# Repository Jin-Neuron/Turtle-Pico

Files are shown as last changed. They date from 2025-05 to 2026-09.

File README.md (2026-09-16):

<div align="right">
  <a href="README_en.md">English</a> | <b>日本語</b>
</div>

# Turtle Pico - 配線いらずで、本格的な電子工作を -

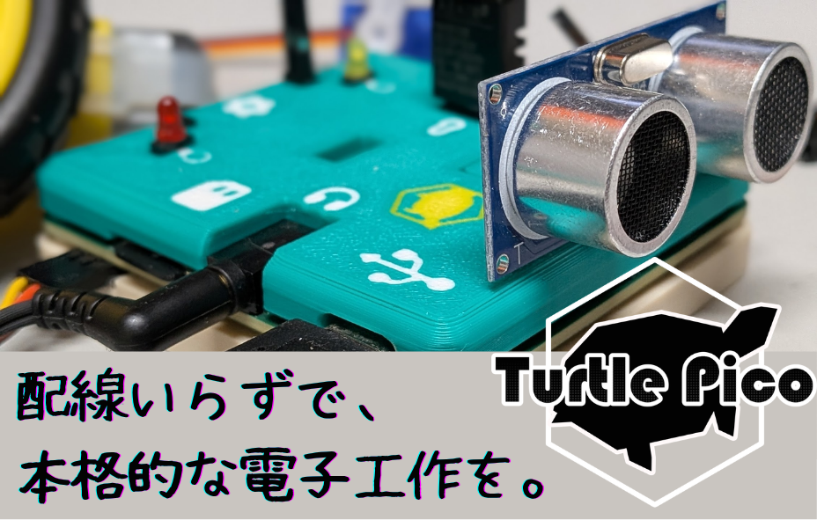
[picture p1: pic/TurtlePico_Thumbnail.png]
Turtle Pico


こんにちは！皆さんは、**電子工作でのお困りごと**を、どのように解決しますか？

煩雑な配線、難しいプログラミングと困難な環境構築、毎回確認が面倒なピン配置...などなど、電子工作を楽しんでいると、いくつもの壁に突き当たります。

そんな課題を克服できるようにと開発したのが、このTurtle Pico マイコンボード。ブレッドボードすら不要で、**コネクタに直接部品を接続するだけ**で回路が完成します。内部には**Raspberry Pi Pico W**を搭載しているので、プログラミングには**MicroPython**を使用でき、更にリソースにも困りません！

コネクタに超音波センサを指すと、その容姿はまるで亀のようで、その容姿から「**Turtle Pico**」とボードを名付けました。

ボードの詳細仕様は、 [Turtle Pico 仕様書](https://jinproduction.work/wp-content/uploads/2024/07/specific_ja.pdf)をご覧ください！

**本PJは現在、製品化に向けて準備中です。**

## Turtle Pico 製品パッケージ

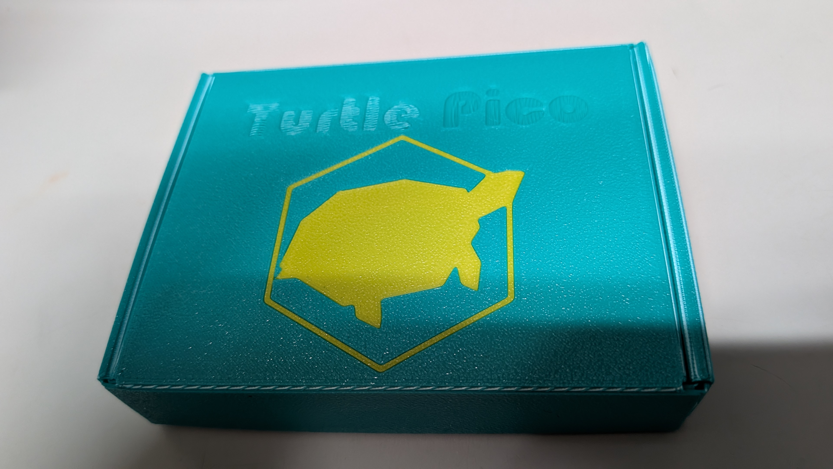
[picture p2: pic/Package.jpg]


Turtle Picoは、画像のような**パッケージ**に収納されています。

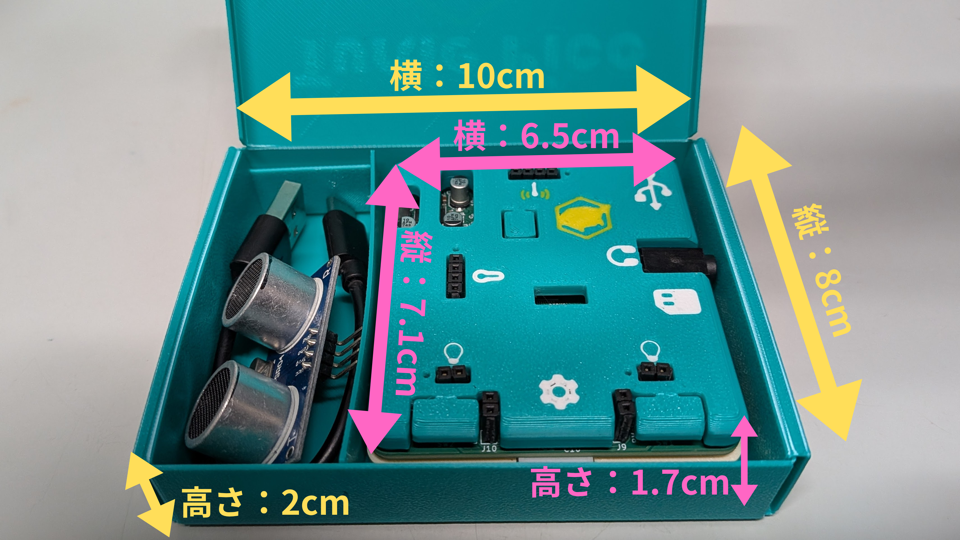
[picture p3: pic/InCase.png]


中を開けるとこのようになっていて、本体と外箱の寸法は画像に記載のとおりです。黄色が外箱、ピンクが本体の寸法です。

パッケージの中に、更にTurtle Pico本体がありますが、本体は基板を**オリジナル3Dプリンタ製カバー**で覆うような形状をしています。USBやMicroSDカードなどのコネクタポートがロゴで表示されています。

それぞれの意味は、[Turtle Pico 仕様書](https://jinproduction.work/wp-content/uploads/2024/07/specific_ja.pdf) にてご確認ください。

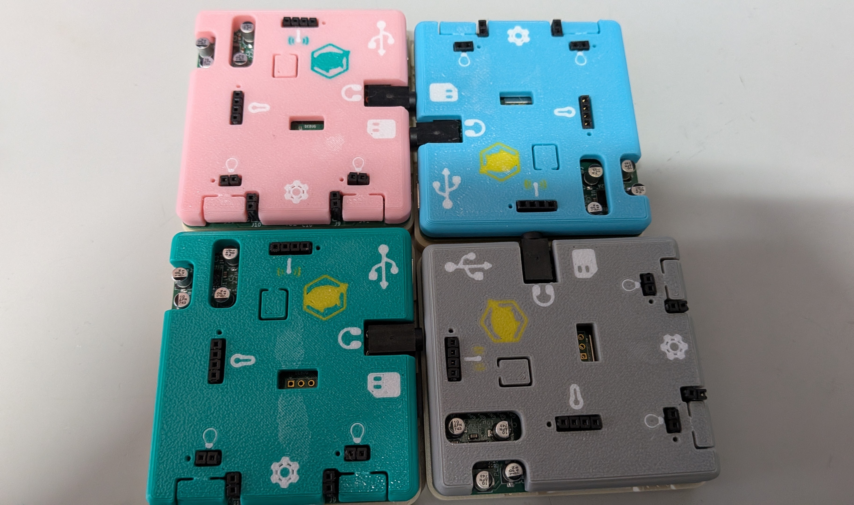
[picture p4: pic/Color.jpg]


Turtle Picoは本体カバーの色で**カラーバリエーション**が4色あり、**ピンク色、緑色、グレー、空色**となっています。

## Turtle Pico ワクワク作例ブック

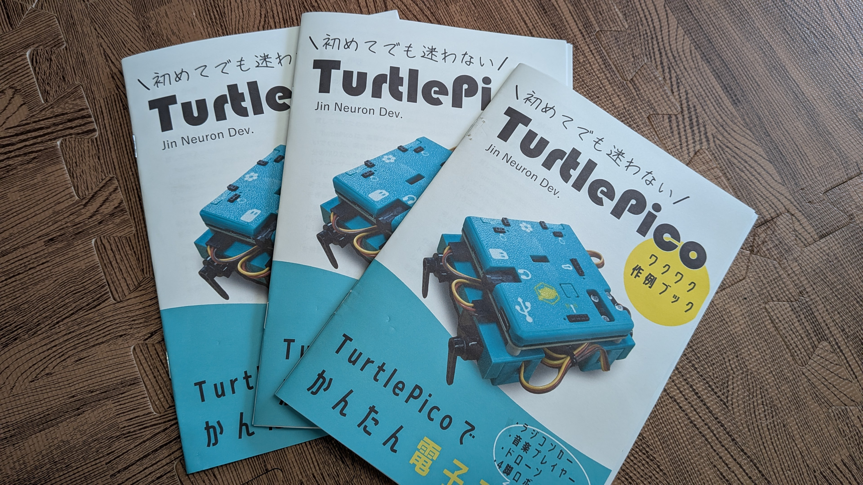
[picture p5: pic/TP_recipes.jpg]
Recipes


製品化モデルでは、上記の作例集が付属します。ソースコードを [example](./example/)に掲載している、TurtlePico作例の数々の作り方を掲載しています。

ここでは、作例集に掲載している、いくつかの**Turtle Picoの仲間たち**をご紹介しましょう。

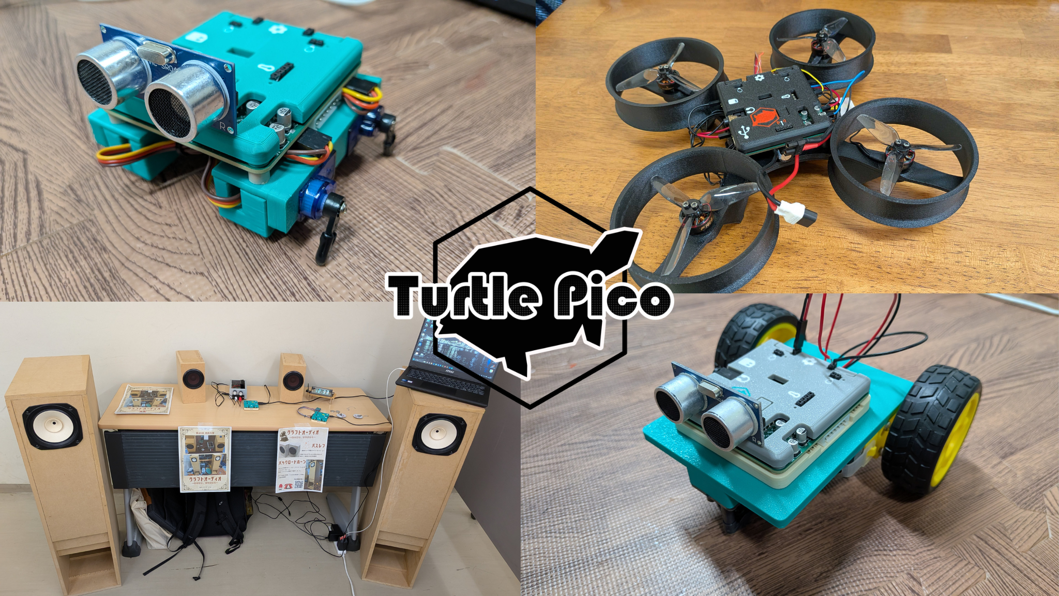
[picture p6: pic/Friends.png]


画像左上は4脚でよちよちと歩くロボット「**Turtle Pico Robot**」で、サーボモータの回転で歩きます。その右側にあるのはドローン「**Turtle Pico Drone**」、更にその下にはマイコンカー「**Turtle Pico Car**」があります。

これらは、上に乗せるものを変えたり、様々な制御を追加することで、**いろいろな応用**が効きそうです。ぜひ、作例集を参考に、**自分専用のアプリケーション**に仕上げてください！

画像左下には、Turtle Picoを**サウンドカード**にしてスピーカーで音楽を流している作例です。Turtle Picoに搭載されているPCM5102AというオーディオDACは、**32bit / 192kHz**にも対応しているため、ハイレゾ音源も流せるパワフルなオーディオDACとなります。

従って、TurtlePicoは、公式にある**サウンドカード**のファームウェアを使用すれば、周囲にアンプやスピーカーをつないで、**クラフトオーディオ**を楽しむことができるボードにもなります。

作例集では、これら作例の作り方を始めとし、**応用の仕方を設計からデバッグまで**、最近の「**バイブコーディング**」でかんたんに行う**製作方法**を解説しています。Turtle Picoをお買い上げいただければ、セット担っているので、ぜひお買い求めください！

<!-- 

## Case

![case](board/main/pic/Case2.PNG)

Turtle Pico Package is available in [**board/main/Case**](https://github.com/Jin-Neuron/Turtle-Pico/tree/master/board/main/Case).

## Purchase your board

![image](https://github.com/user-attachments/assets/7ed59ffb-0fa4-4088-b02c-0e429f06822e)

Turtle Pico boards can currently only be purchased from [PCBWay's Shared Project Page](https://www.pcbway.com/project/shareproject/Turtle_Pico_Board_c183b11f.html). Once officially released, we plan to make it available for purchase at various online stores. 

-->

## License

本公式リポジトリは、複数のライセンスにて構成されています。

[LICENSE File](License.txt)にてご確認ください。

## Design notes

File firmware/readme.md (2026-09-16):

 build command
 
`$ cd path/to/micropython/ports/rp2`
 
`$ make BOARD=TurtlePico BOARD_DIR=../../../Turtle-Pico/firmware/board_TurtlePico_W USER_C_MODULES=../../../Turtle-Pico/firmware/micropython.cmake -j4`

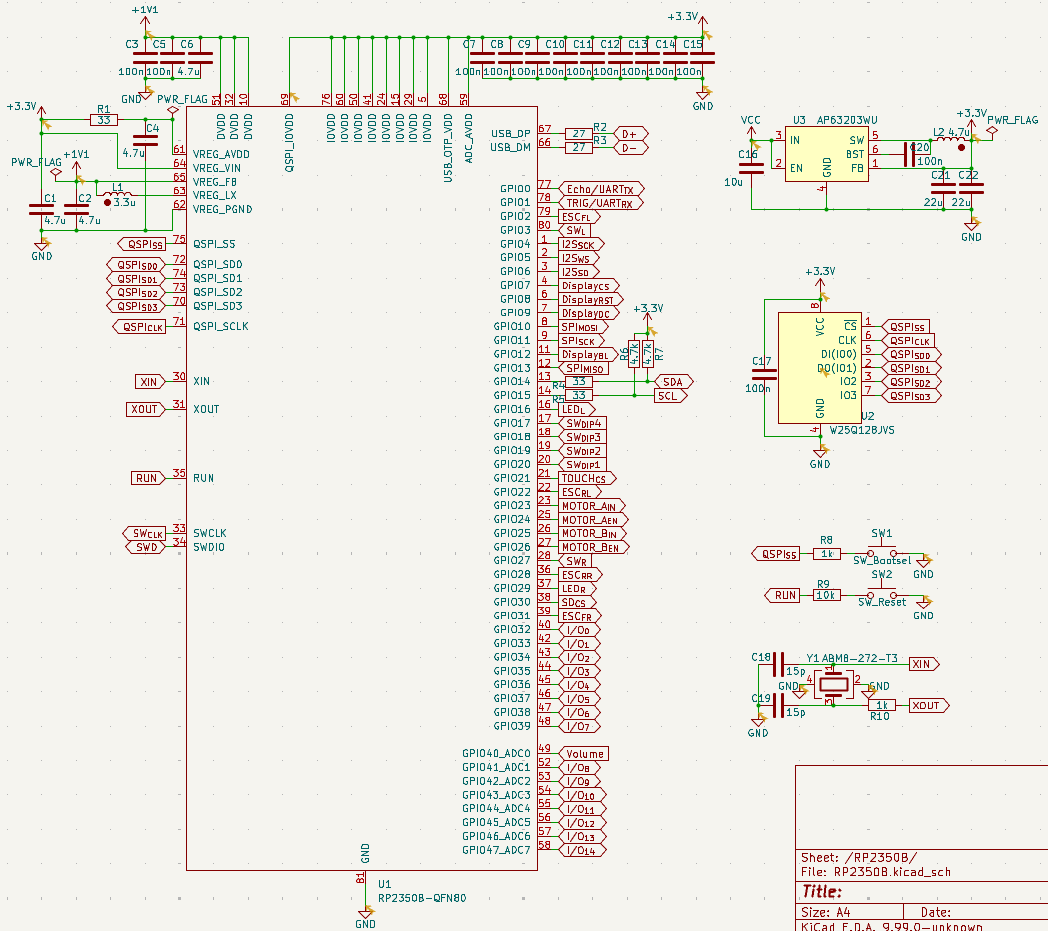
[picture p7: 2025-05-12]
board/advanced/pic/schematics/MainPart_RP2350B.png

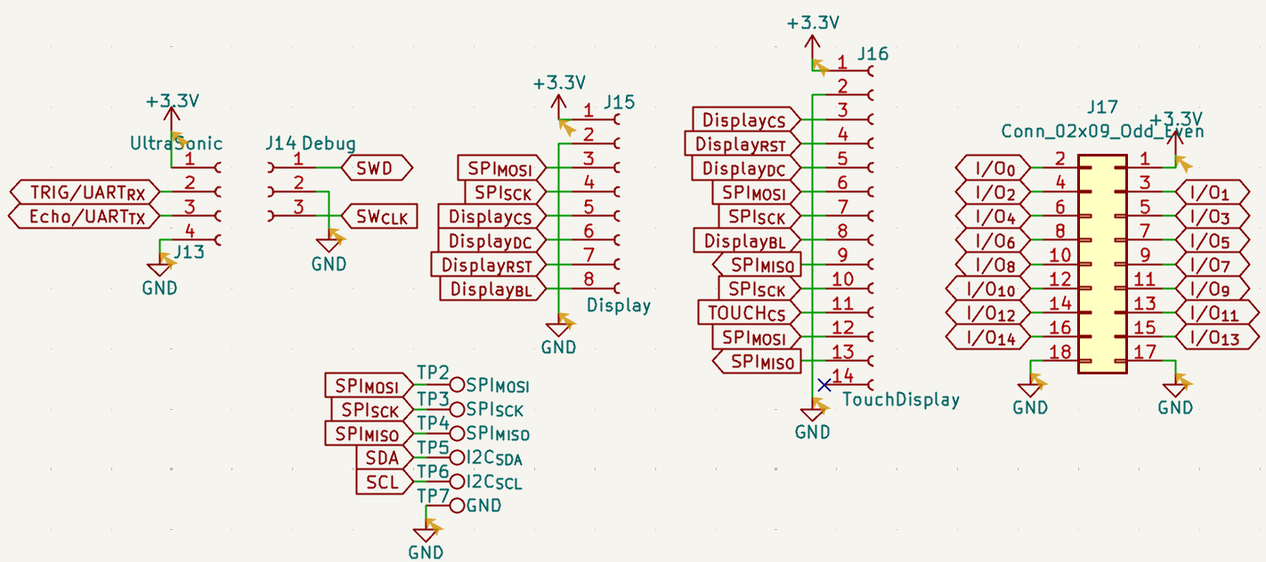
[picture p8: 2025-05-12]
board/advanced/pic/schematics/ConnectorPart.png

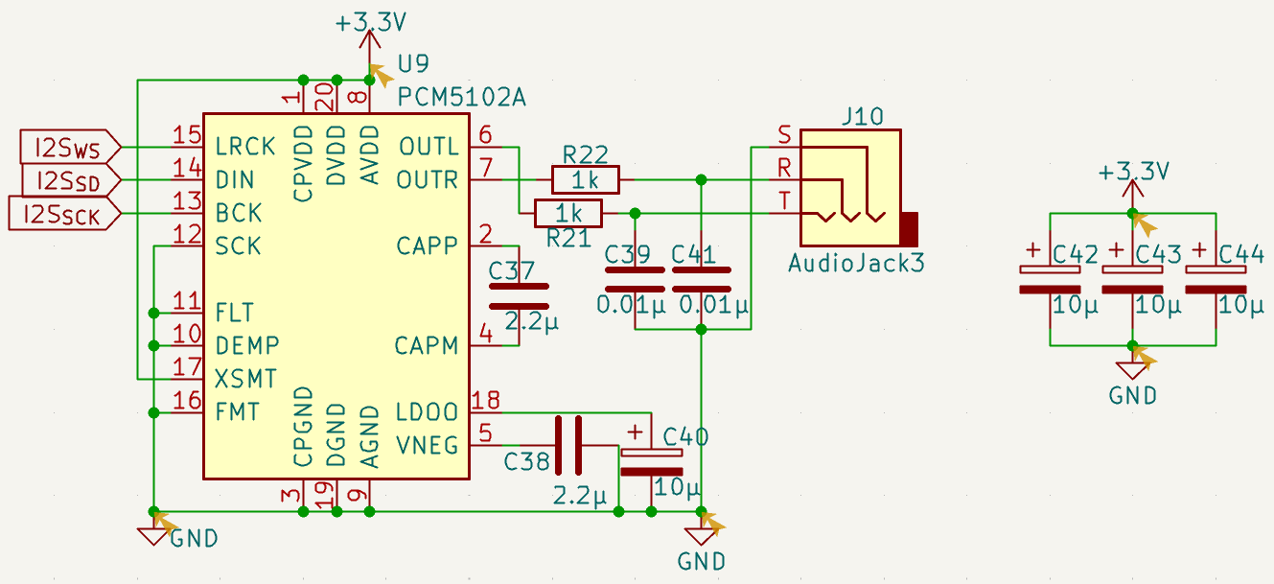
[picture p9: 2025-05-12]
board/advanced/pic/schematics/AudioPart.png

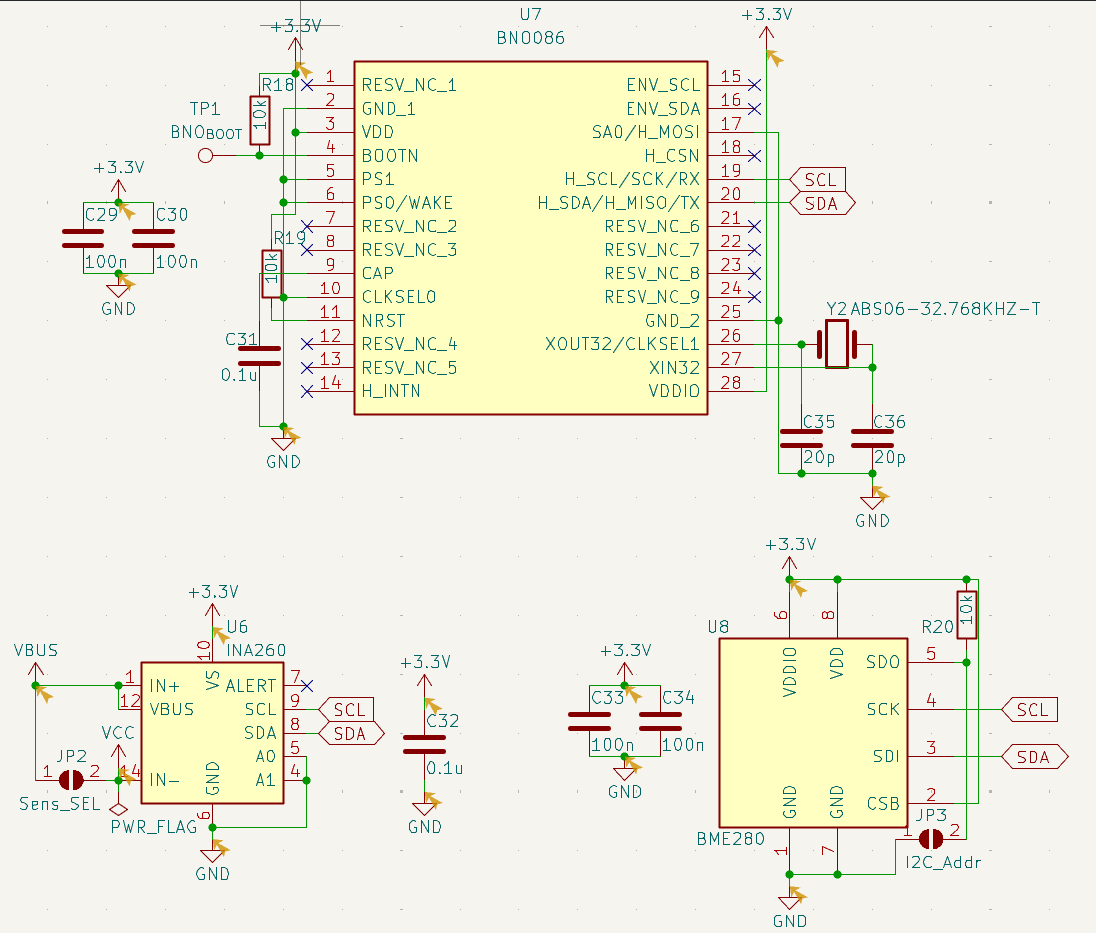
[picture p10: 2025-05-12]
board/advanced/pic/schematics/SensorPart.png

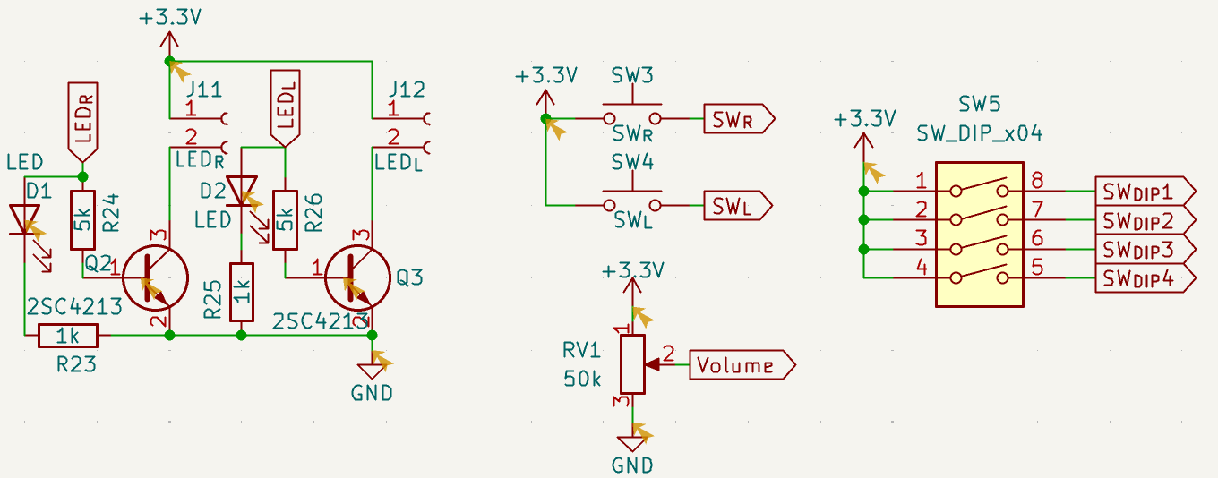
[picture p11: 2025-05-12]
board/advanced/pic/schematics/LED_SW_Part.png

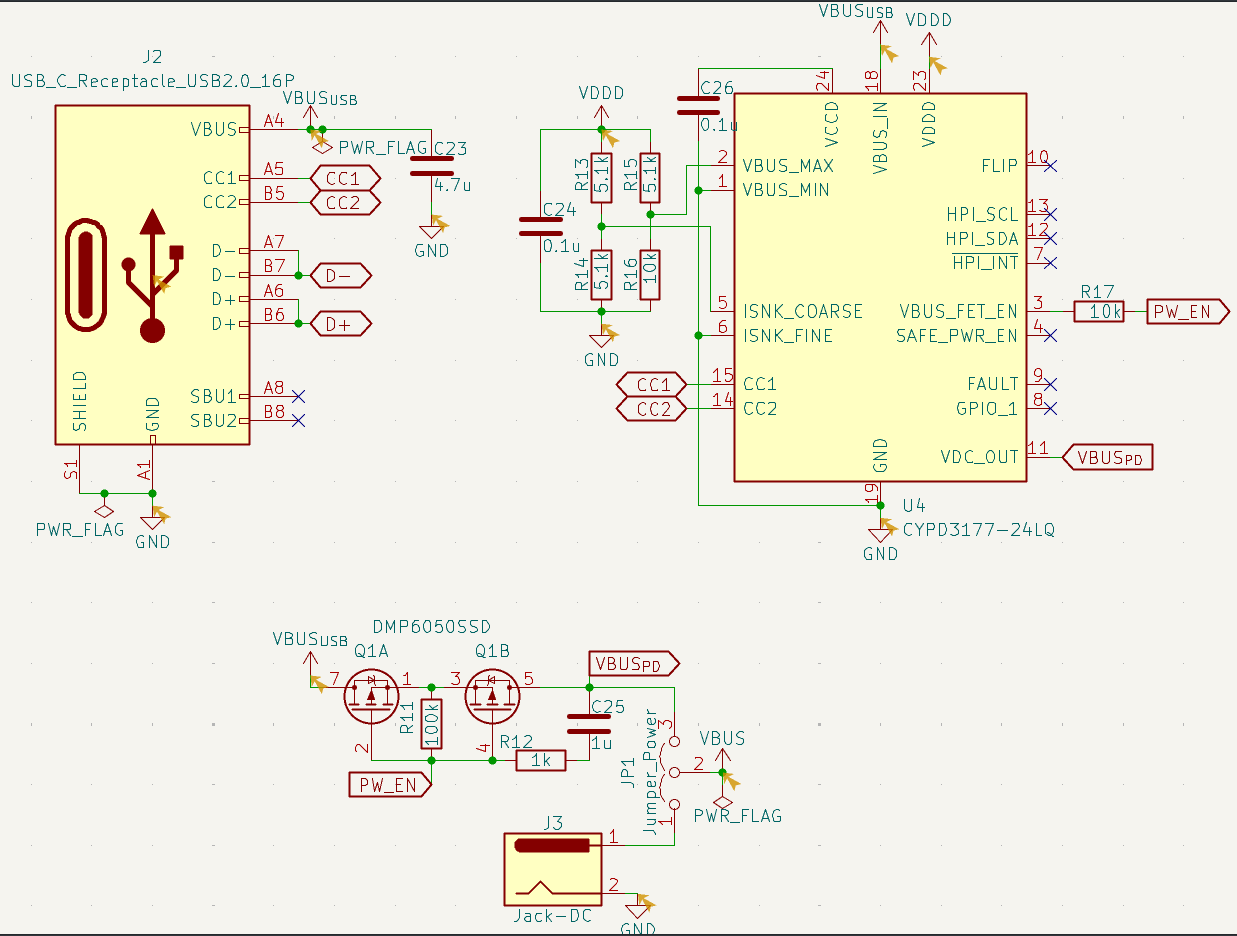
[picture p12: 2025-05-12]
board/advanced/pic/schematics/PowerPart.png

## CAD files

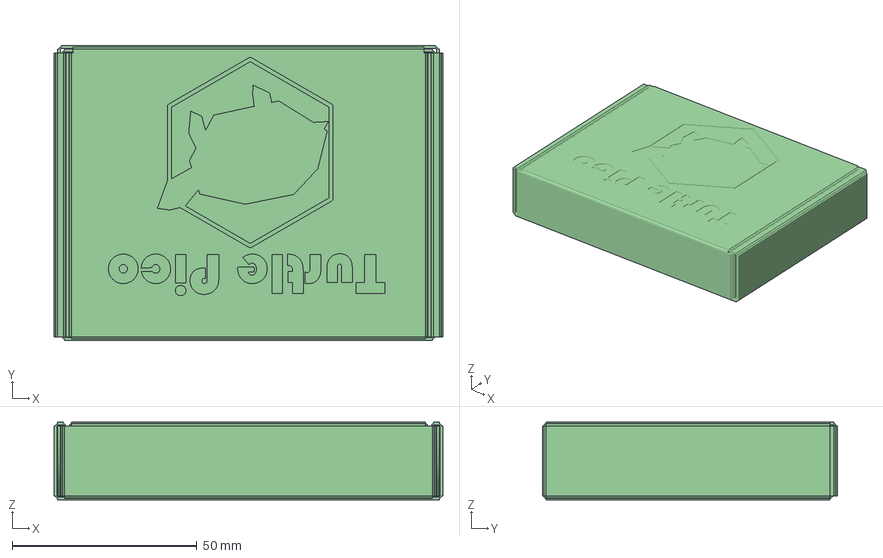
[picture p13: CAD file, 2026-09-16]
board/main/Case/Package_Base_asm.3mf
105.4 x 80.0 x 21.0 mm

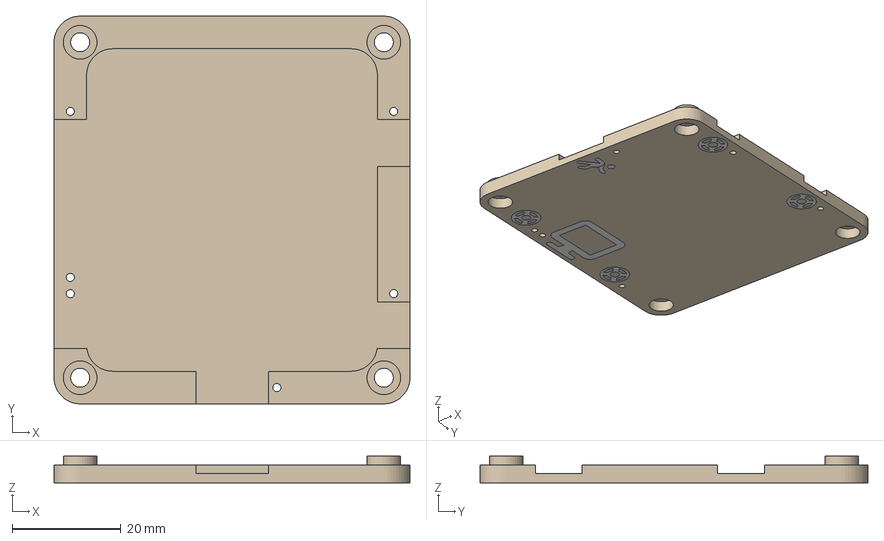
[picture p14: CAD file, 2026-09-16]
board/main/Case/LowerCase_LowQI.3mf
65.5 x 71.3 x 4.89 mm
ボディ1
ボディ2
ボディ3
ボディ4
ボディ5
ボディ6
ボディ7
ボディ9
下段

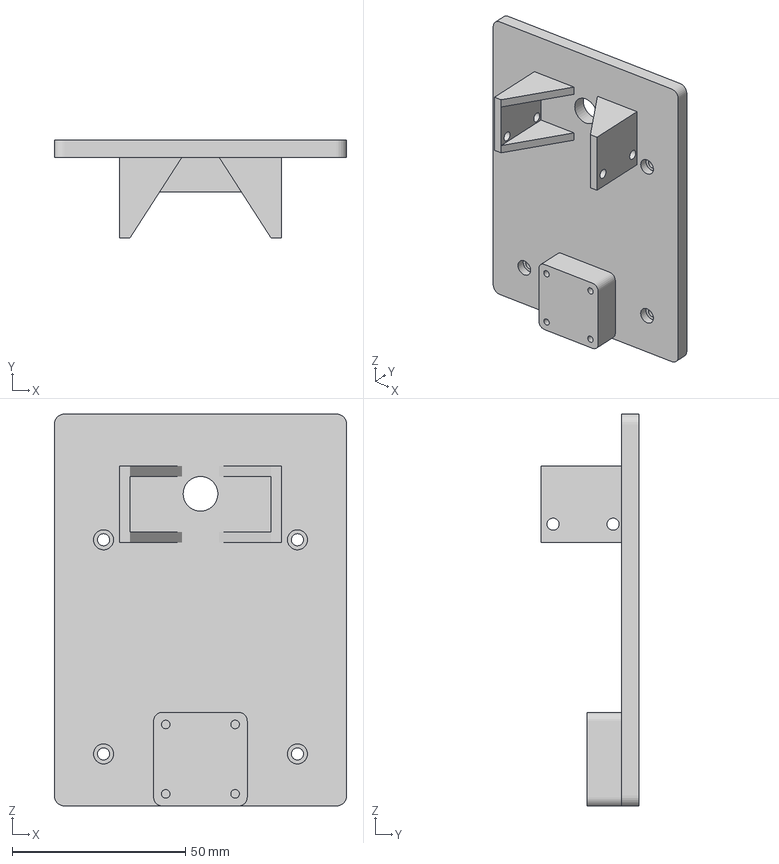
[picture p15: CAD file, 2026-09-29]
example/Car/3D_Data/CarBody.3mf
84.3 x 28.3 x 113.0 mm

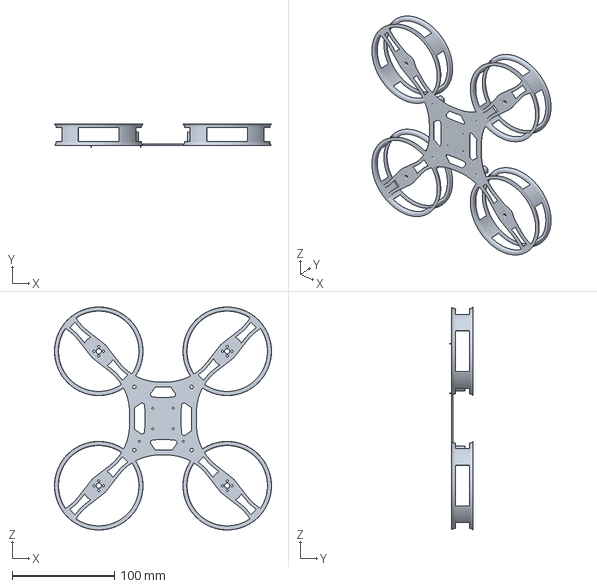
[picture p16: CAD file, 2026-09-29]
example/Drone/3D_Data/DroneUpper.3mf
212.0 x 22.8 x 217.8 mm

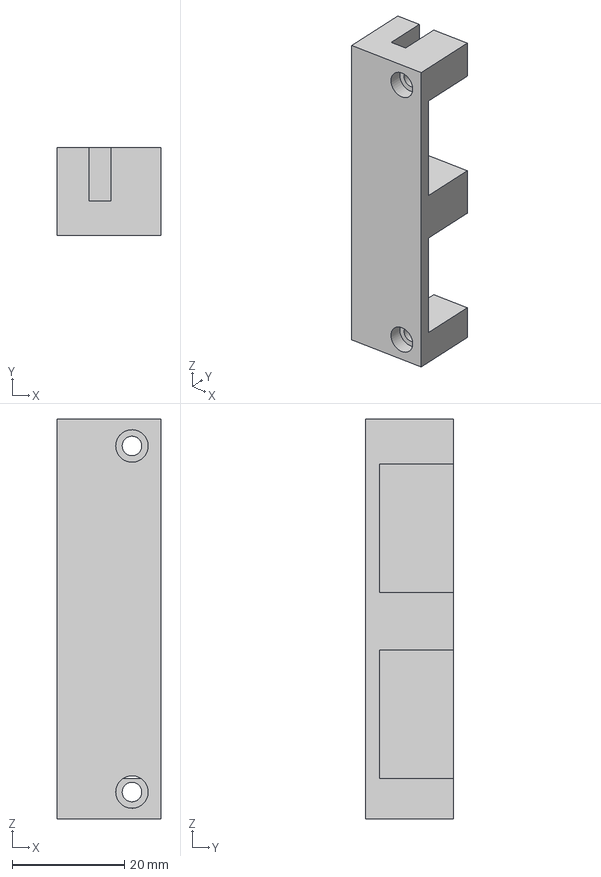
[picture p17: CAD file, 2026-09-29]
example/Robot/3D_Data/Bottom.3mf
18.5 x 15.7 x 71.3 mm

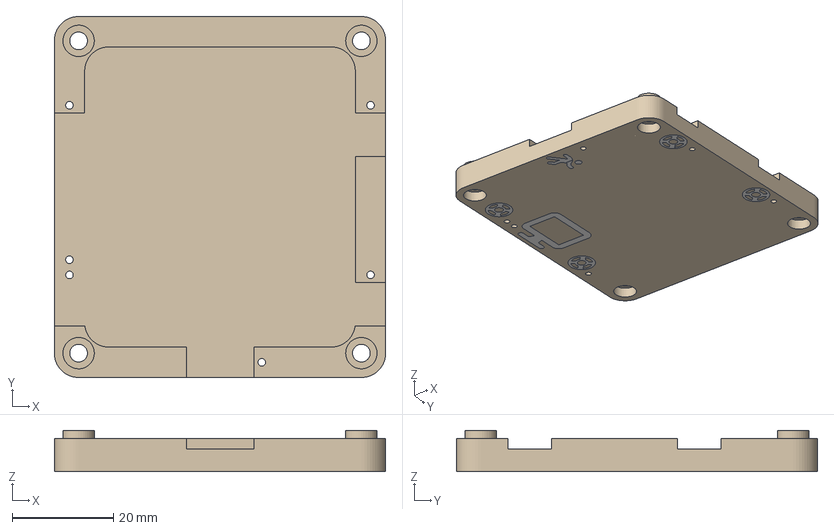
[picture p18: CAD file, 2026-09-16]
board/main/Case/LowerCase_HighQI.3mf
65.5 x 71.3 x 8.19 mm
ボディ1
ボディ2
ボディ3
ボディ4
ボディ5
ボディ6
ボディ7
ボディ9
下段

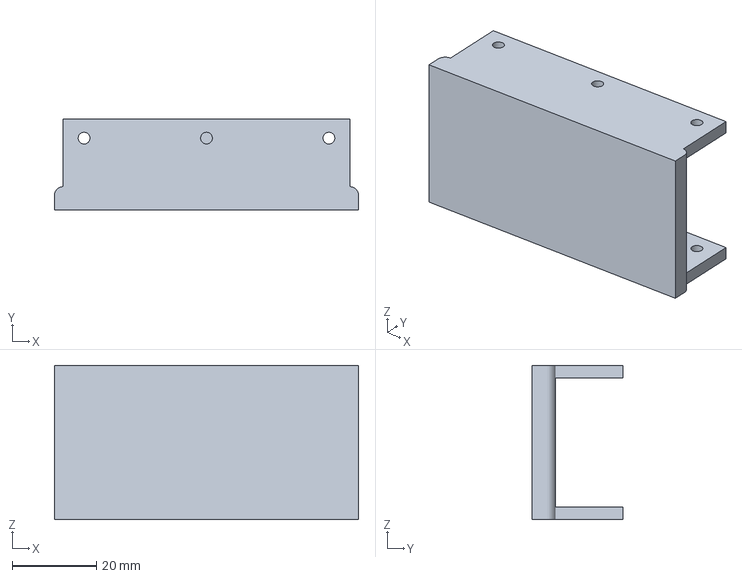
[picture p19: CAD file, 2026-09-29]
example/Drone/3D_Data/BatCase.3mf
72.0 x 21.5 x 36.5 mm

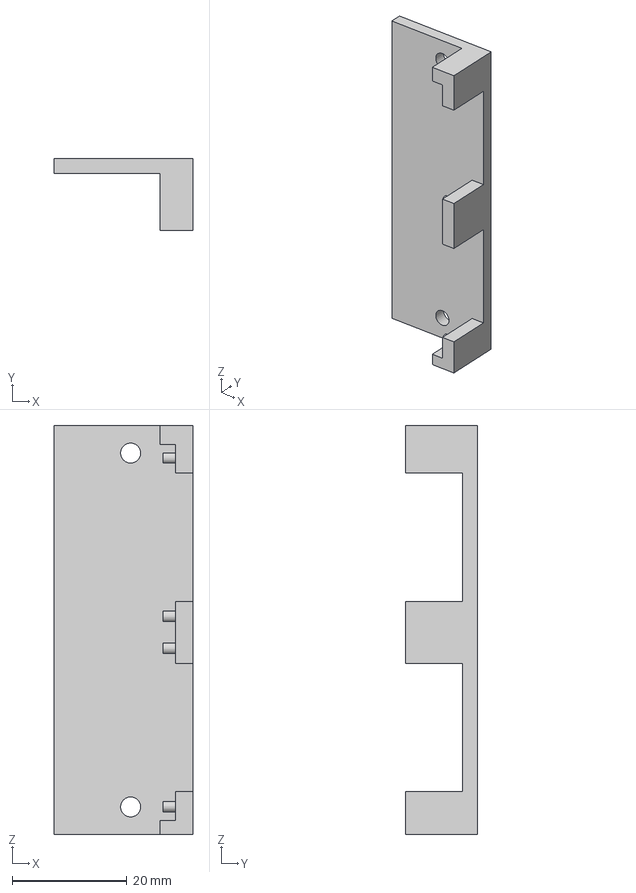
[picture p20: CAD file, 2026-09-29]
example/Robot/3D_Data/Top.3mf
24.2 x 12.6 x 71.3 mm

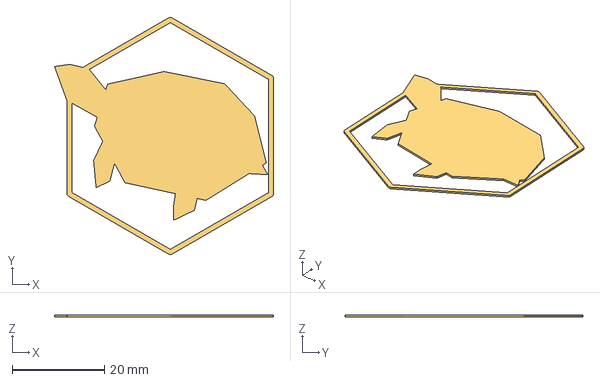
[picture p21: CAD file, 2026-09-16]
board/main/Case/Package_Logo.3mf
47.6 x 51.6 x 0.4 mm

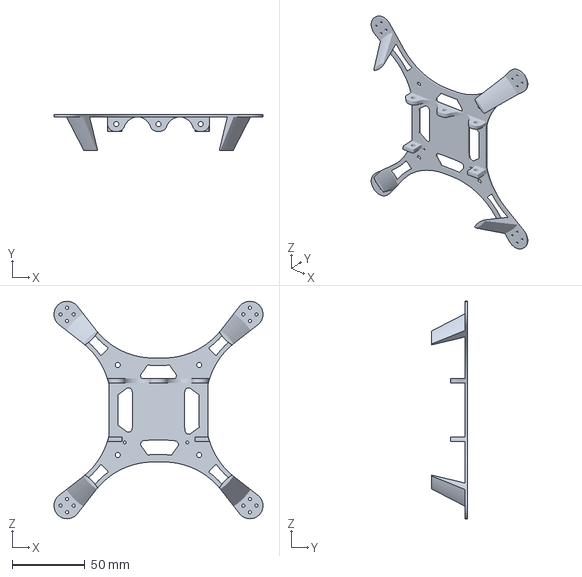
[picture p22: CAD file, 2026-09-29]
example/Drone/3D_Data/DroneBottom_v2.3mf
143.5 x 24.5 x 149.3 mm

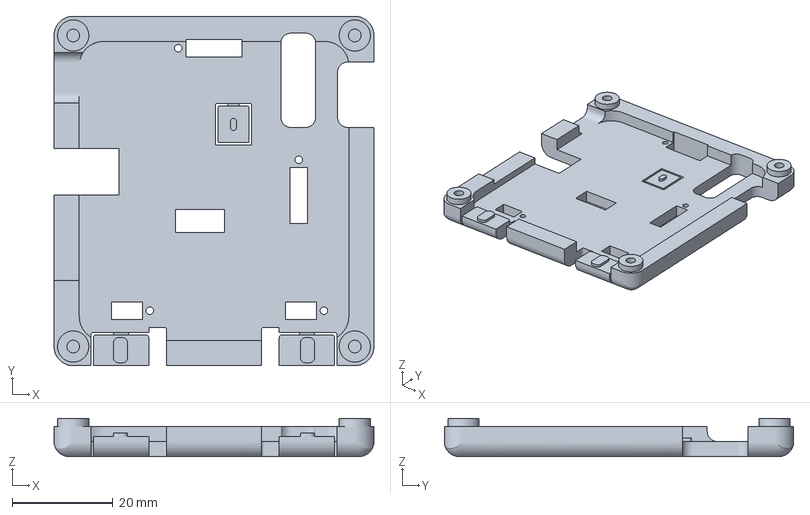
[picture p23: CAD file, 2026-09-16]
board/main/Case/UpperCase.3mf
63.5 x 69.3 x 7.60 mm

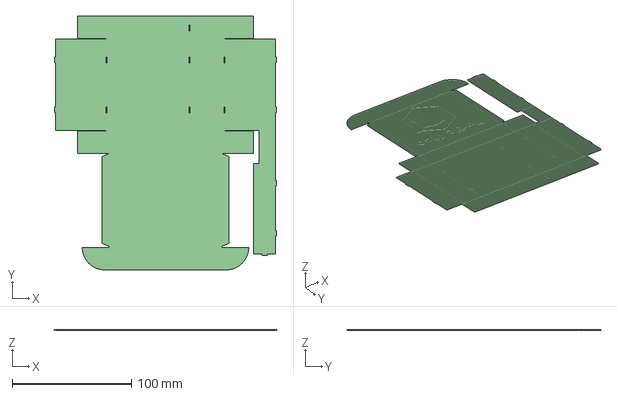
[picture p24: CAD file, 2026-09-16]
board/main/Case/Package_Base.3mf
186.5 x 213.3 x 0.8 mm

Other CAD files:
board/main/TurtlePico_nw/TurtlePico_nw.step
board/main/TurtlePico_v1.2.step
board/main/Case/LowerCase_XH.3mf
board/main/TurtlePico_v1.1.step
board/main/Case/UpperCase_old.step
board/main/Case/LowerCase_old.step

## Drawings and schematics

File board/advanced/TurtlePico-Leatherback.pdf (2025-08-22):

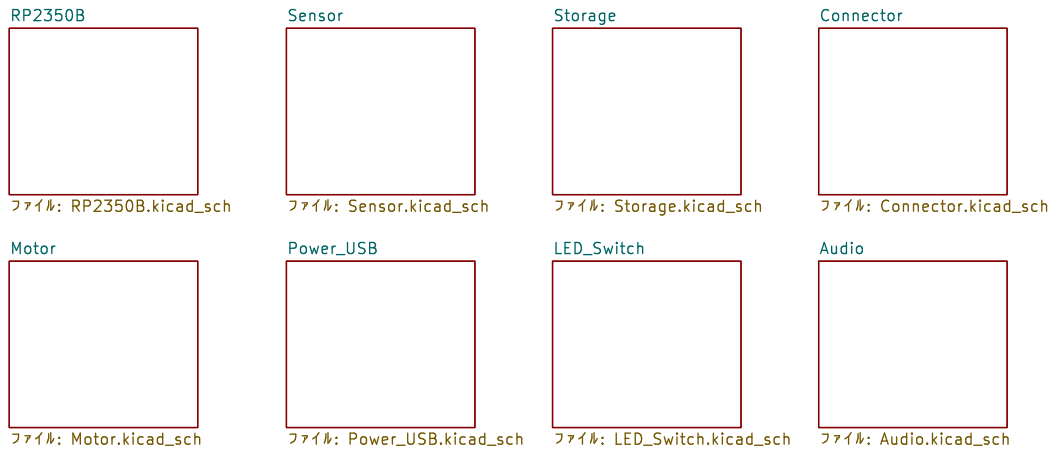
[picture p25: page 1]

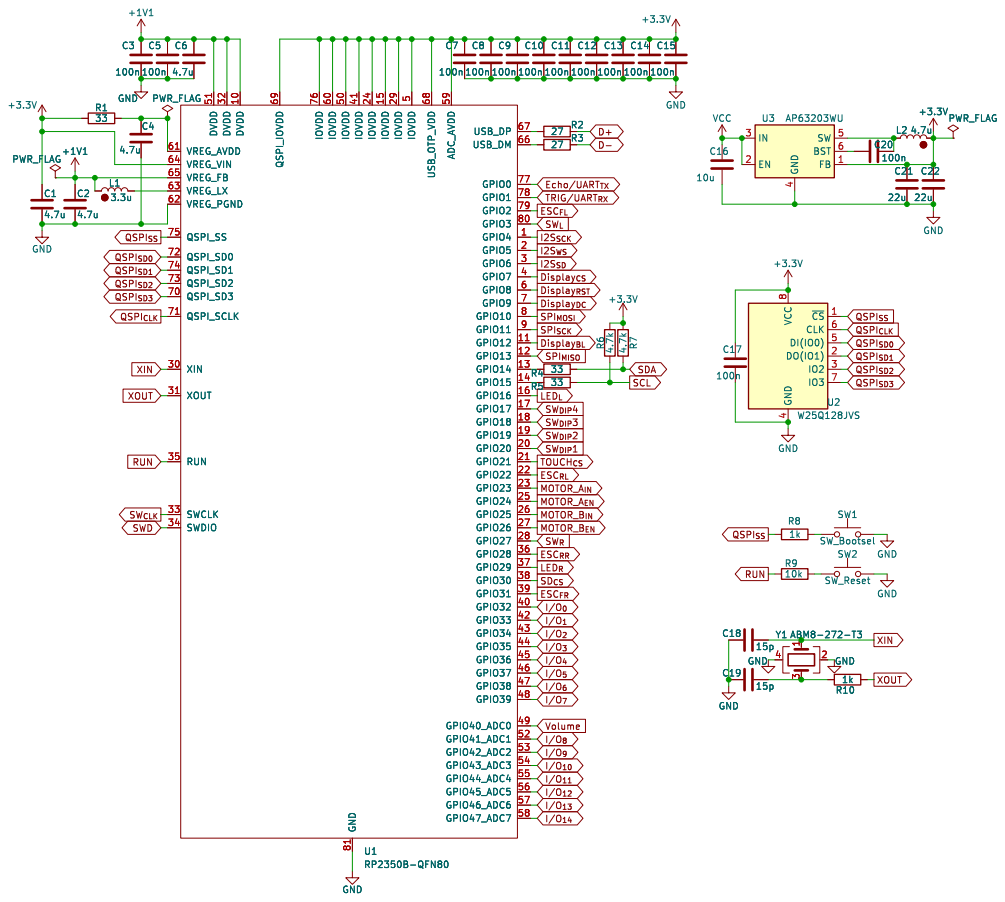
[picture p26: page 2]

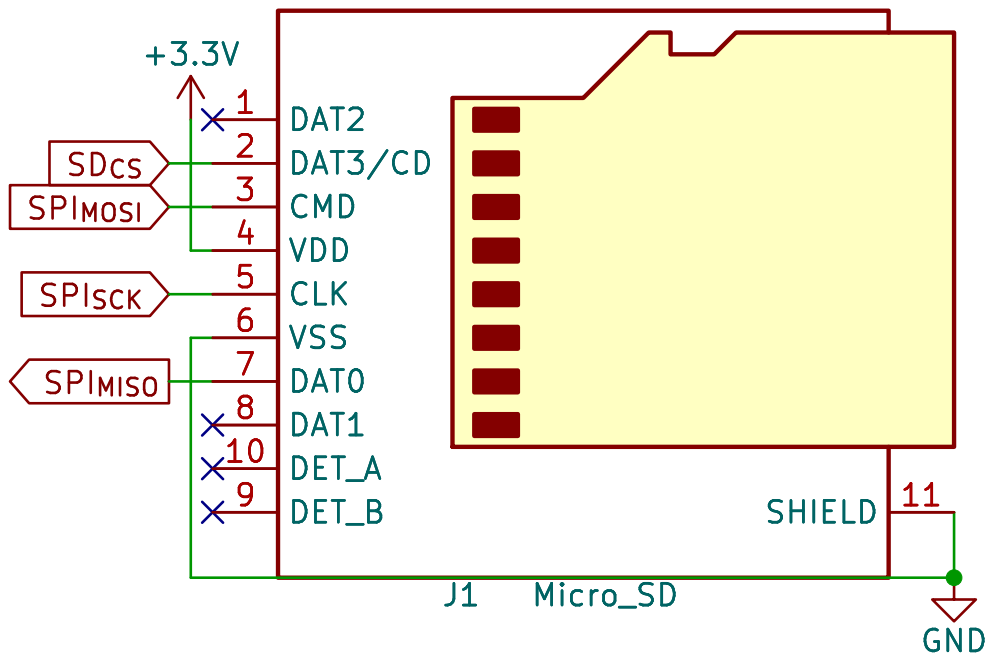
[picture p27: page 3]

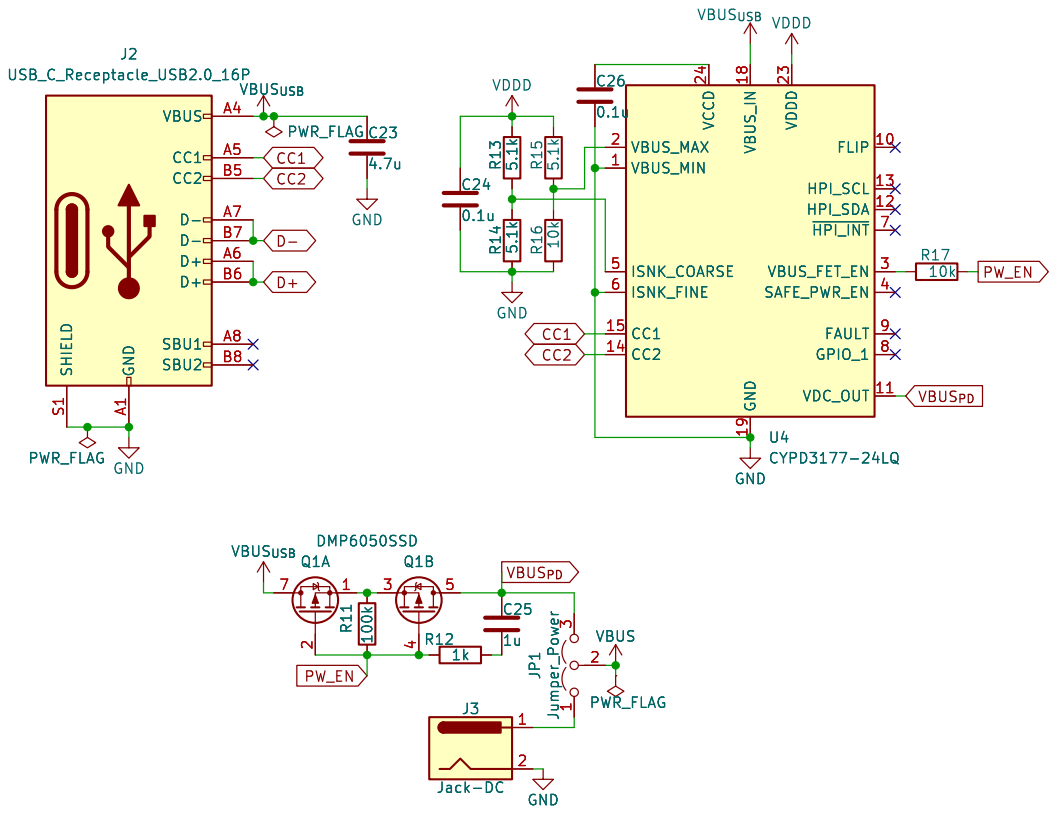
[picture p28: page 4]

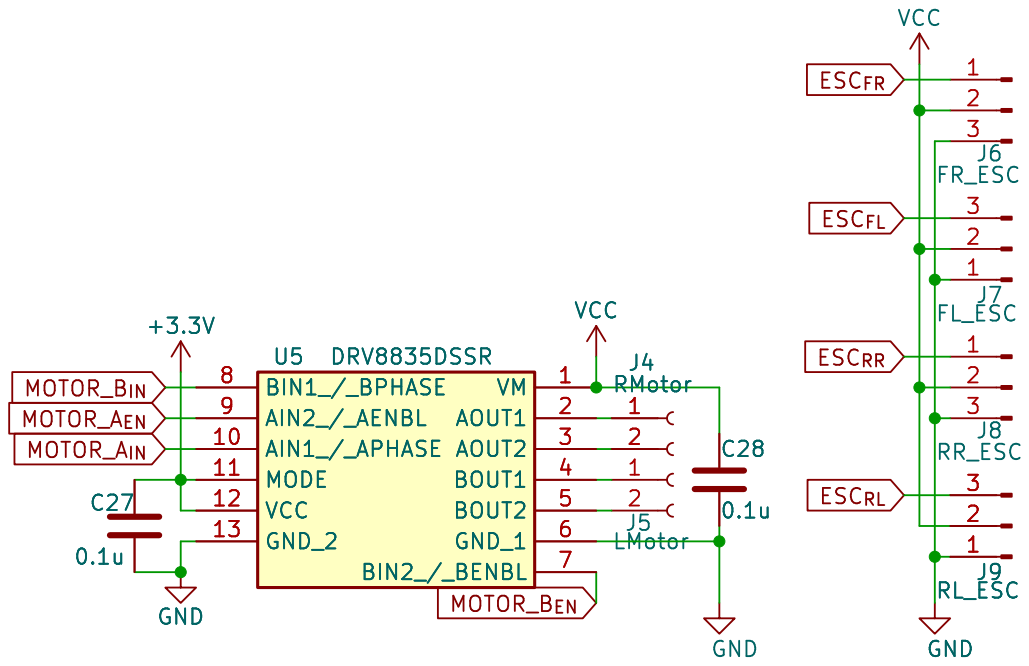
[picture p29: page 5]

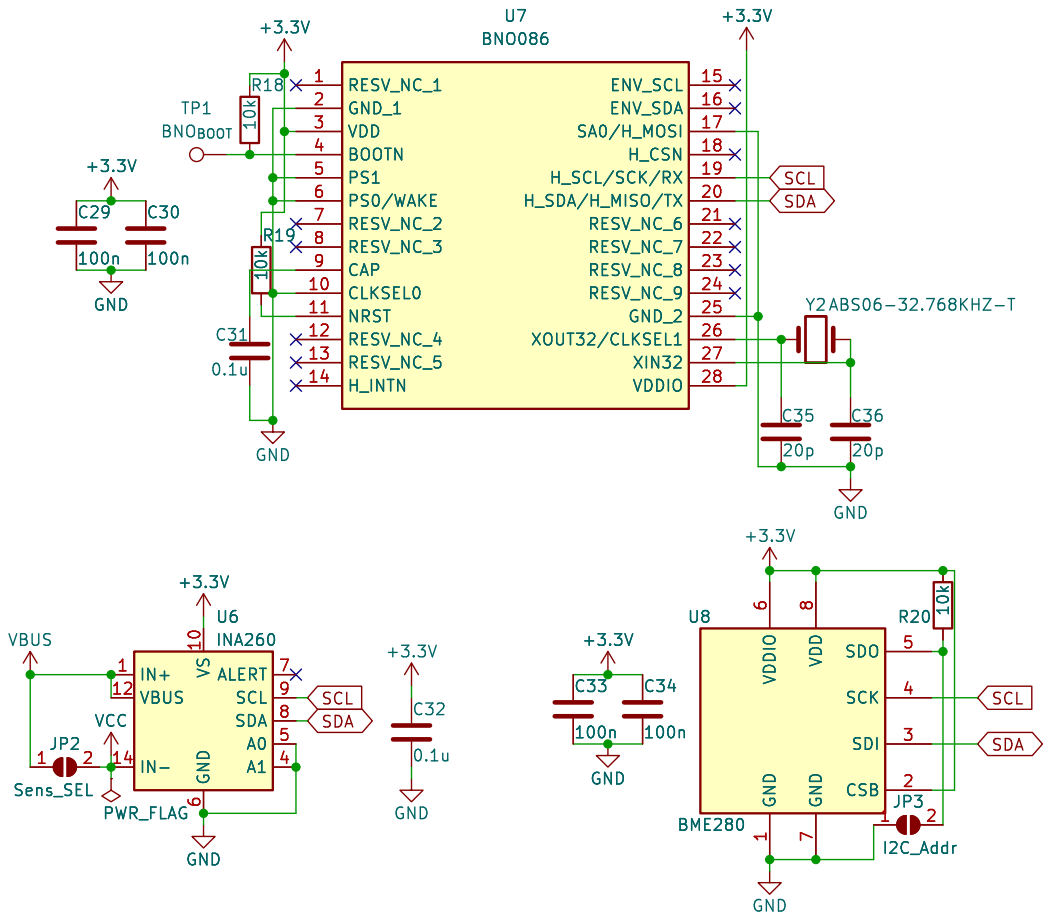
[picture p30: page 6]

7 SDO 5 SCK 4 SDI 3 CSB 2 U8 BME280 1 2

7 SDO 5 SCK 4 SDI 3 CSB 2

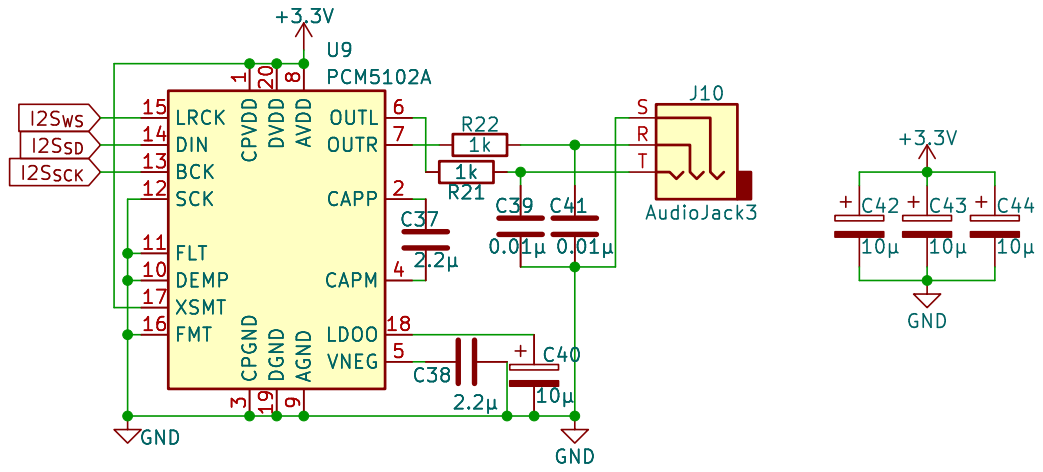
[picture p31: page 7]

9 OUTL 6 OUTR 7 CAPP 2 CAPM 4

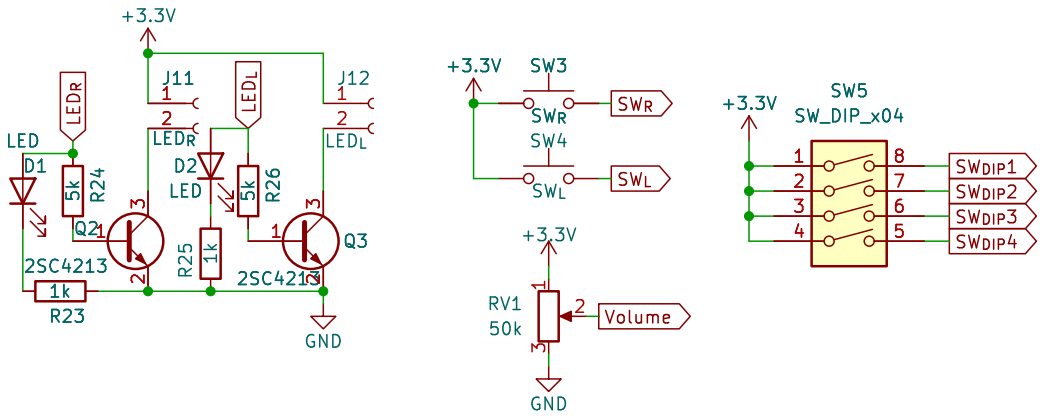
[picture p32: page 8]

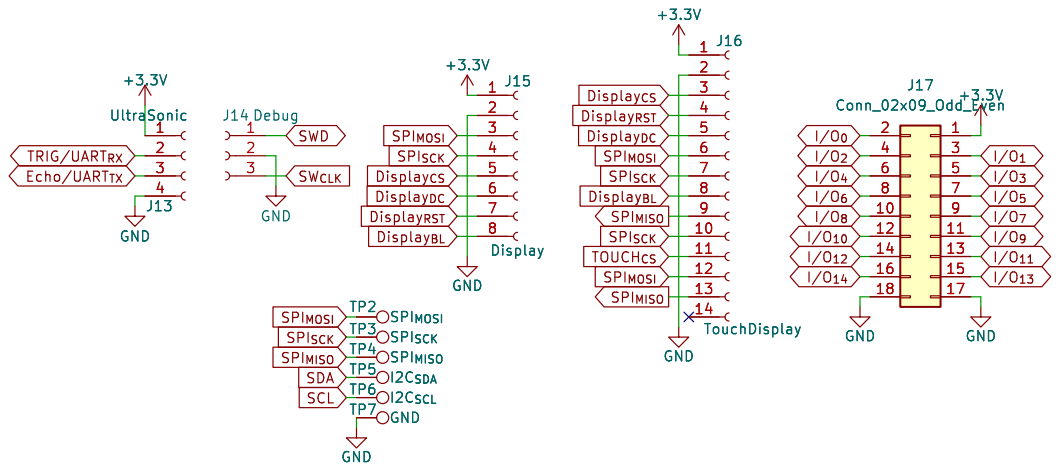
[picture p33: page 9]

SCL SPI_{MOSI} GND GND

TP3 SPI_{SCK} TP6 I2C_{SCL} TP4 SPI_{MISO} TP7 GND

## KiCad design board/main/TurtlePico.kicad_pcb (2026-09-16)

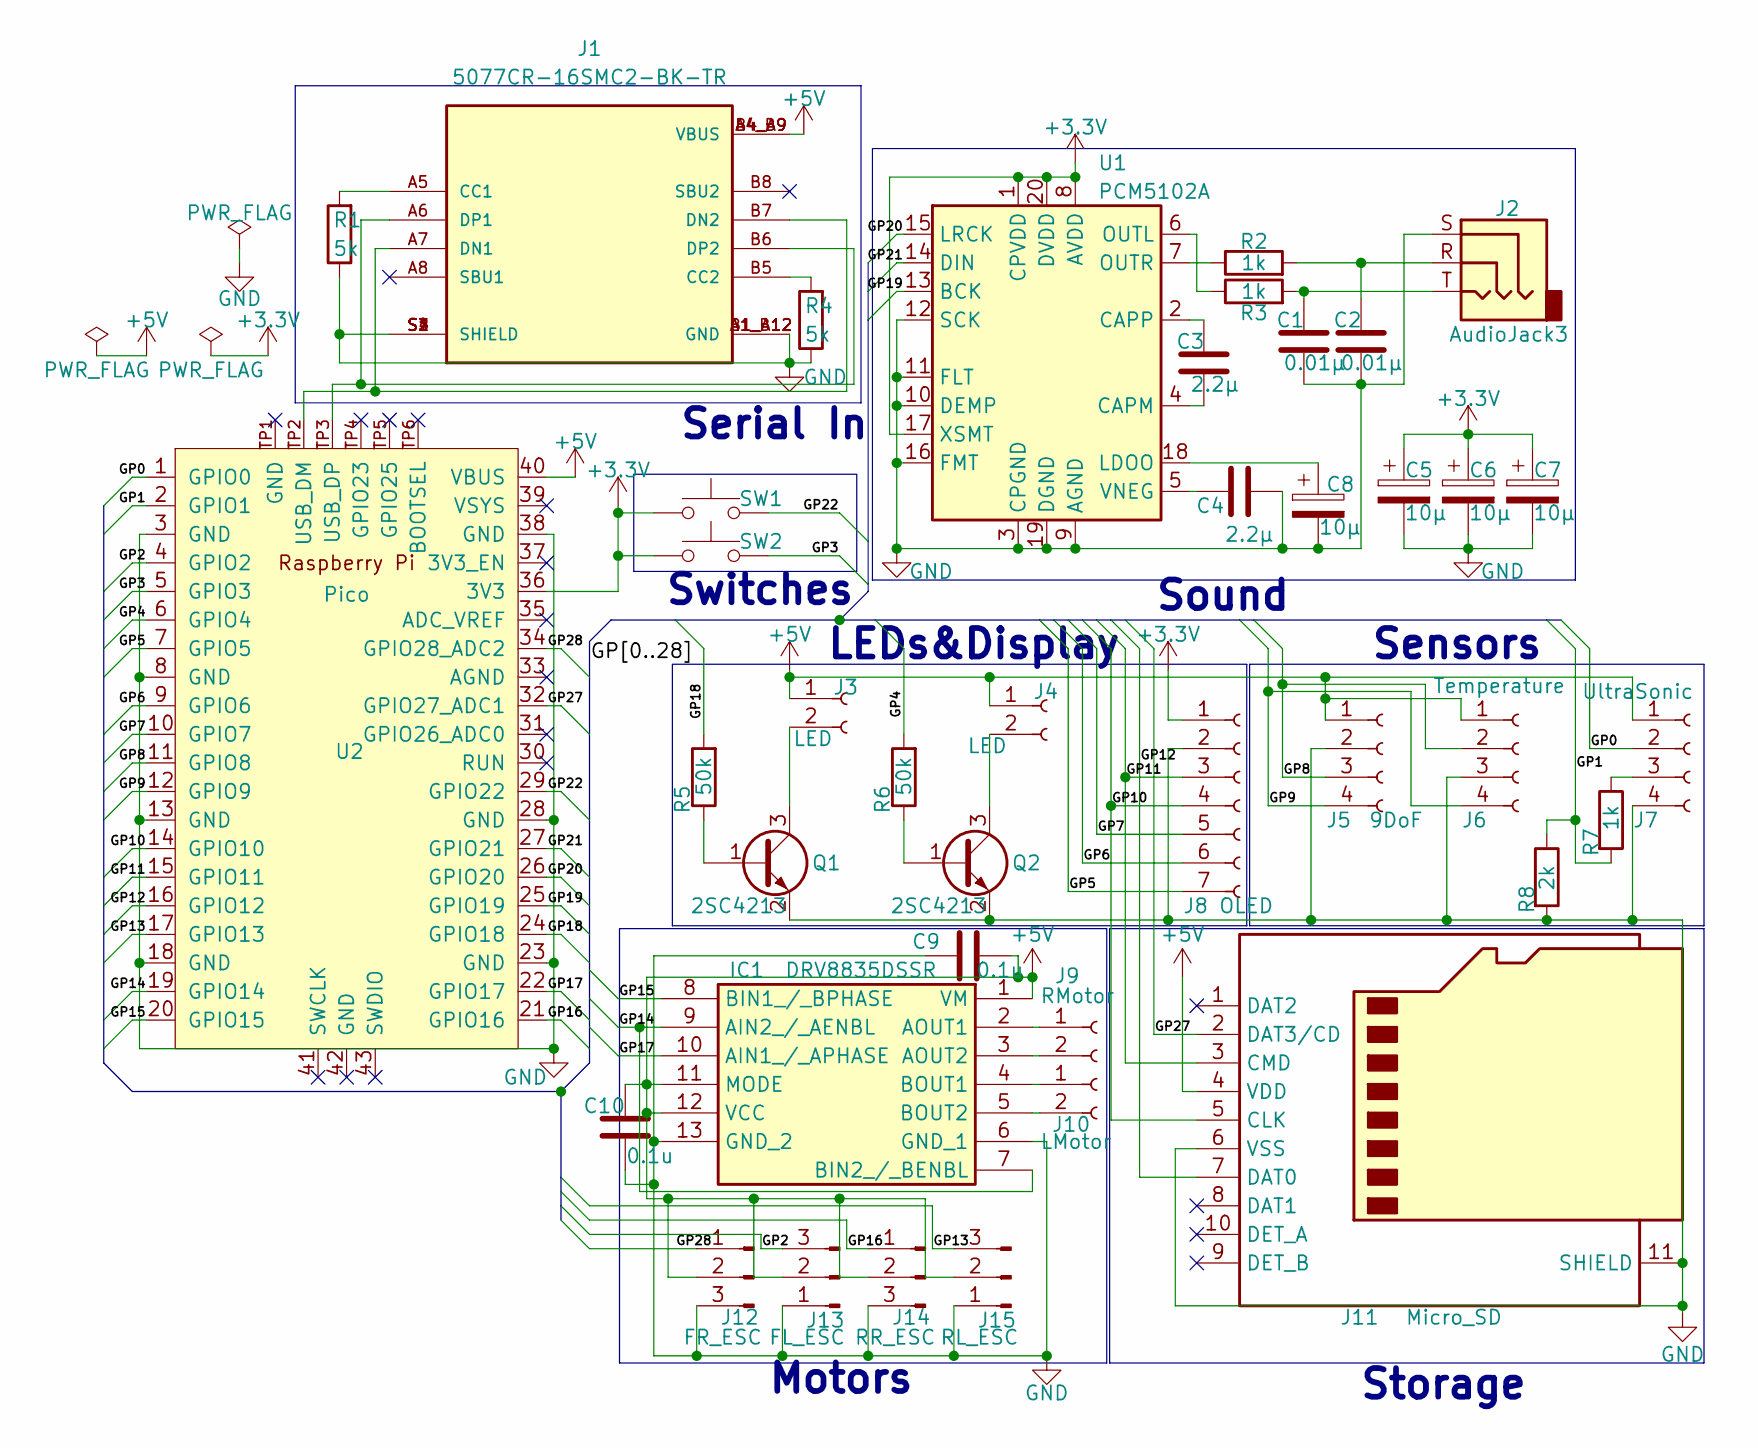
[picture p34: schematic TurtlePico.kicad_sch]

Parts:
C1, C2: 0.01µ; C_0603_1608Metric; Manufacturer_Part_Number GCM188R71H103KA37J; Mouser Part Number 81-GCM188R71H103KA7J
C3, C4: 2.2µ; C_0603_1608Metric; Manufacturer_Part_Number GRM188R61H225KE11D; Mouser Part Number 81-GRM188R61H225KE1D
C5, C6, C7, C8: 10µ; CP_Elec_4x5.4; Manufacturer_Part_Number EEE-FN1A100R; Mouser Part Number 667-EEE-FN1A100R
C9, C10: 0.1u; C_0603_1608Metric; Manufacturer_Part_Number GCM188R71C104KA37J; Mouser Part Number 81-GCM188R71C104KA7J
IC1: DRV8835DSSR; Mouser Part Number 595-DRV8835DSSR
J1: 5077CR-16SMC2-BK-TR; NELTRON_5077CR-16SMC2-BK-TR; Manufacturer_Part_Number USB4105-GF-A-060; Mouser Part Number 640-USB4105-GF-A-060
J2: AudioJack3; STX3000; Manufacturer_Part_Number STX-3000; Mouser Part Number 806-STX-3000
J3, J4: LED; PinSocket_1x02_P2.54mm_Vertical
J5: 9DoF; JST_XH_S4B-XH-A_1x04_P2.50mm_Horizontal
J6: Temperature; PinSocket_1x04_P2.54mm_Vertical
J7: UltraSonic; PinSocket_1x04_P2.54mm_Vertical
J8: OLED; JST_XH_S7B-XH-A_1x07_P2.50mm_Horizontal
J9: RMotor; PinSocket_1x02_P2.54mm_Vertical
J10: LMotor; PinSocket_1x02_P2.54mm_Vertical
J11: Micro_SD; microSD_HC_Hirose_DM3AT-SF-PEJM5; Manufacturer_Part_Number DM3AT-SF-PEJM5; Mouser Part Number 798-DM3AT-SF-PEJM5
J12: FR_ESC; PinHeader_1x03_P2.54mm_Horizontal
J13: FL_ESC; PinHeader_1x03_P2.54mm_Horizontal
J14: RR_ESC; PinHeader_1x03_P2.54mm_Horizontal
J15: RL_ESC; PinHeader_1x03_P2.54mm_Horizontal
Q1, Q2: 2SC4213; SOT-323_SC-70; Manufacturer_Part_Number 2SC4213-A(TE85L,F); Mouser Part Number 757-2SC4213-ATE85LF
R1, R4: 5k; R_0603_1608Metric; Manufacturer_Part_Number RN73H1JTTD5101D100; Mouser Part Number 660-RN73H1JT5101D100
R2, R3, R7: 1k; R_0603_1608Metric; Manufacturer_Part_Number RN73H1JTTD1001F100; Mouser Part Number 660-RN73H1JT1001F100
R5, R6: 50k; R_0603_1608Metric; Manufacturer_Part_Number RN73H1JTTD5102F100; Mouser Part Number 660-RN73H1JT5102F100
R8: 2k; R_0603_1608Metric; Manufacturer_Part_Number RN73H1JTTD2001F25; Mouser Part Number 660-RN73H1JTD2001F25
SW1, SW2: SW_Push; SW_SKRPACE010; Manufacturer_Part_Number SKRPACE010; Mouser Part Number 688-SKRPACE010
U1: PCM5102A; TSSOP-20_4.4x6.5mm_P0.65mm; Manufacturer_Part_Number PCM5102APWR; Mouser Part Number 595-PCM5102APWR
U2: Pico; RPi_Pico_SMD_TH; Manufacturer_Part_Number SC0918; Mouser Part Number 358-SC0918

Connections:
+3.3V: C5.1, C6.1, C7.1, J8.1, SW1.1, SW2.1, U1.1 (CPVDD), U1.8 (AVDD), U1.17 (XSMT), U1.20 (DVDD), U2.36 (3V3)
+5V: C9.1, C10.1, IC1.1 (VM), IC1.11 (MODE), IC1.12 (VCC), J1.A4_B9 (VBUS), J1.B4_A9 (VBUS), J3.1, J4.1, J5.1, J6.1, J7.1, J11.4 (VDD), J12.2, J13.2, J14.2, J15.2, U2.40 (VBUS)
/GP0: J7.2, U2.1 (GPIO0)
/GP1: R7.2, R8.1, U2.2 (GPIO1)
/GP2: J13.3, U2.4 (GPIO2)
/GP3: SW2.2, U2.5 (GPIO3)
/GP4: R6.2, U2.6 (GPIO4)
/GP5: J8.7, U2.7 (GPIO5)
/GP6: J8.6, U2.9 (GPIO6)
/GP7: J8.5, U2.10 (GPIO7)
/GP8: J5.3, J6.2, U2.11 (GPIO8)
/GP9: J5.4, J6.4, U2.12 (GPIO9)
/GP10: J8.4, J11.5 (CLK), U2.14 (GPIO10)
/GP11: J8.3, J11.3 (CMD), U2.15 (GPIO11)
/GP12: J11.7 (DAT0), U2.16 (GPIO12)
/GP13: J15.3, U2.17 (GPIO13)
/GP14: IC1.7 (BIN2_/_BENBL), IC1.9 (AIN2_/_AENBL), U2.19 (GPIO14)
/GP15: IC1.8 (BIN1_/_BPHASE), U2.20 (GPIO15)
/GP16: J14.1, U2.21 (GPIO16)
/GP17: IC1.10 (AIN1_/_APHASE), U2.22 (GPIO17)
/GP18: R5.2, U2.24 (GPIO18)
/GP19: U1.13 (BCK), U2.25 (GPIO19)
/GP20: U1.15 (LRCK), U2.26 (GPIO20)
/GP21: U1.14 (DIN), U2.27 (GPIO21)
/GP22: SW1.2, U2.29 (GPIO22)
/GP27: J11.2 (DAT3/CD), U2.32 (GPIO27_ADC1)
/GP28: J12.1, U2.34 (GPIO28_ADC2)
GND: C1.2, C2.2, C4.2, C5.2, C6.2, C7.2, C8.2, C9.2, C10.2, IC1.6 (GND_1), IC1.13 (GND_2), J1.A1_B12 (GND), J1.B1_A12 (GND), J1.S1 (SHIELD), J1.S2 (SHIELD), J1.S3 (SHIELD), J1.S4 (SHIELD), J2.S, J5.2, J6.3, J7.4, J8.2, J11.6 (VSS), J11.11 (SHIELD), J12.3, J13.1, J14.3, J15.1, Q1.2 (E), Q2.2 (E), R1.1, R4.1, R8.2, U1.3 (CPGND), U1.9 (AGND), U1.10 (DEMP), U1.11 (FLT), U1.12 (SCK), U1.16 (FMT), U1.19 (DGND), U2.3 (GND), U2.8 (GND), U2.13 (GND), U2.18 (GND), U2.23 (GND), U2.28 (GND), U2.38 (GND)
unnamed: C1.1, J2.T, R3.2
unnamed: C2.1, J2.R, R2.2
unnamed: IC1.2 (AOUT1), J9.1
unnamed: IC1.3 (AOUT2), J9.2
unnamed: IC1.4 (BOUT1), J10.1
unnamed: IC1.5 (BOUT2), J10.2
unnamed: J1.A5 (CC1), R1.2
unnamed: J1.B5 (CC2), R4.2
unnamed: J1.A7 (DN1), J1.B7 (DN2), U2.TP2 (USB_DM)
unnamed: J1.A6 (DP1), J1.B6 (DP2), U2.TP3 (USB_DP)
unnamed: J3.2, Q1.3 (C)
unnamed: J4.2, Q2.3 (C)
unnamed: J7.3, R7.1
unnamed: Q1.1 (B), R5.1
unnamed: Q2.1 (B), R6.1
unnamed: C3.2, U1.4 (CAPM)
unnamed: C3.1, U1.2 (CAPP)
unnamed: C8.1, U1.18 (LDOO)
unnamed: R3.1, U1.6 (OUTL)
unnamed: R2.1, U1.7 (OUTR)
unnamed: C4.1, U1.5 (VNEG)

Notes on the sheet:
Sensors
LEDs&Display
Serial In
Switches
Motors
Sound
Storage

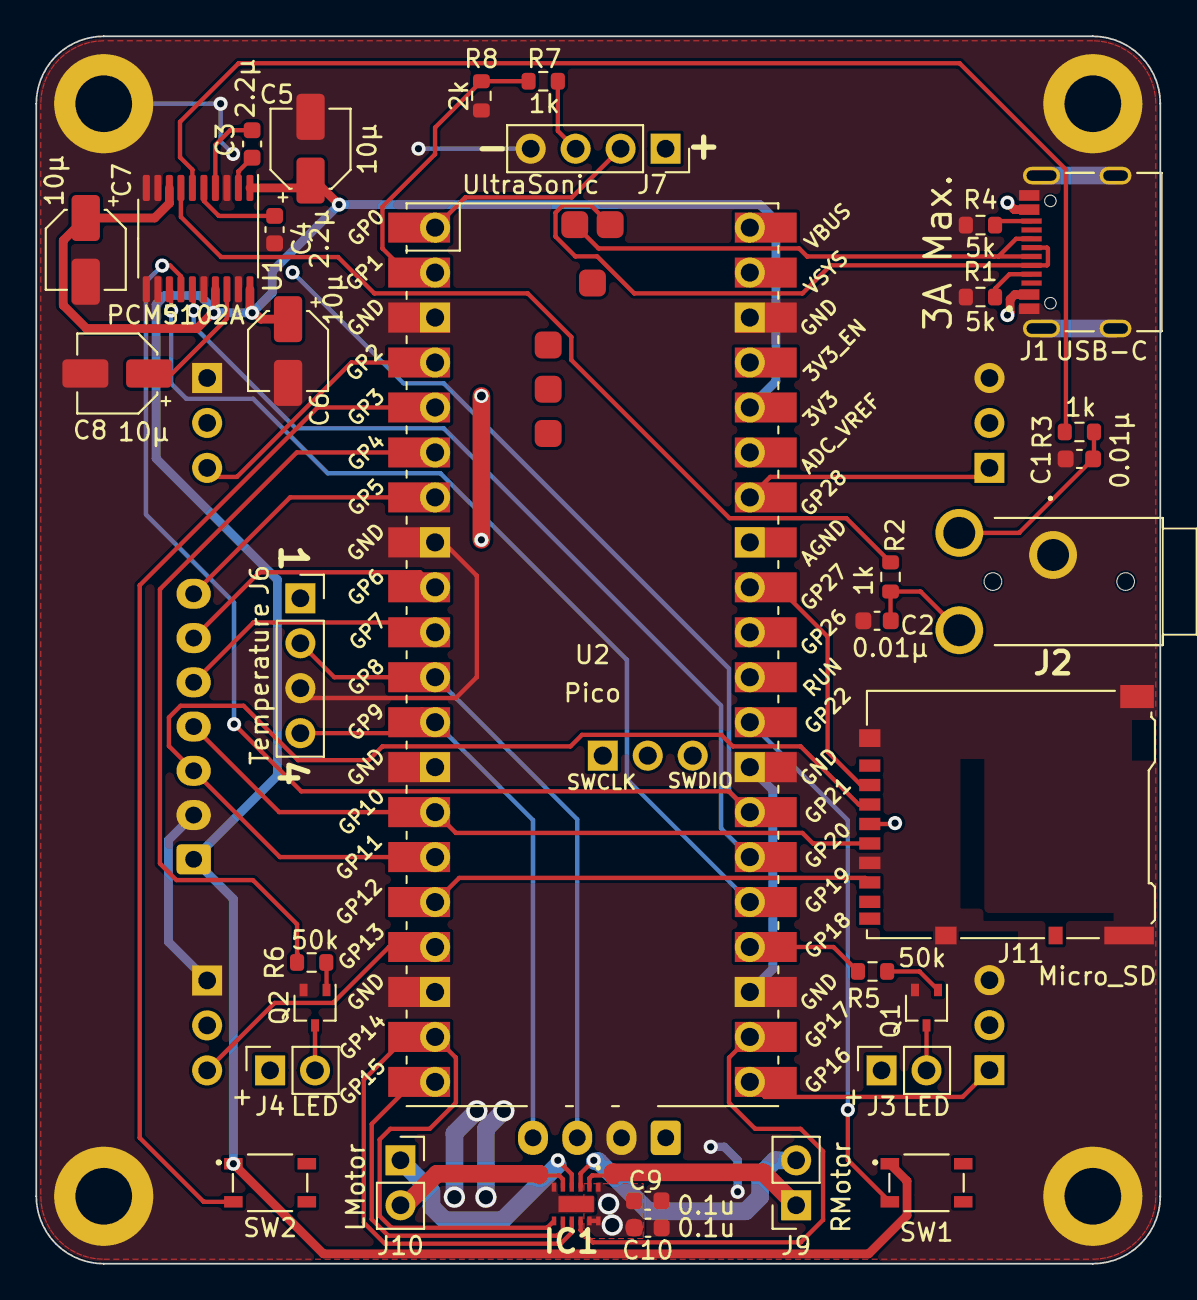
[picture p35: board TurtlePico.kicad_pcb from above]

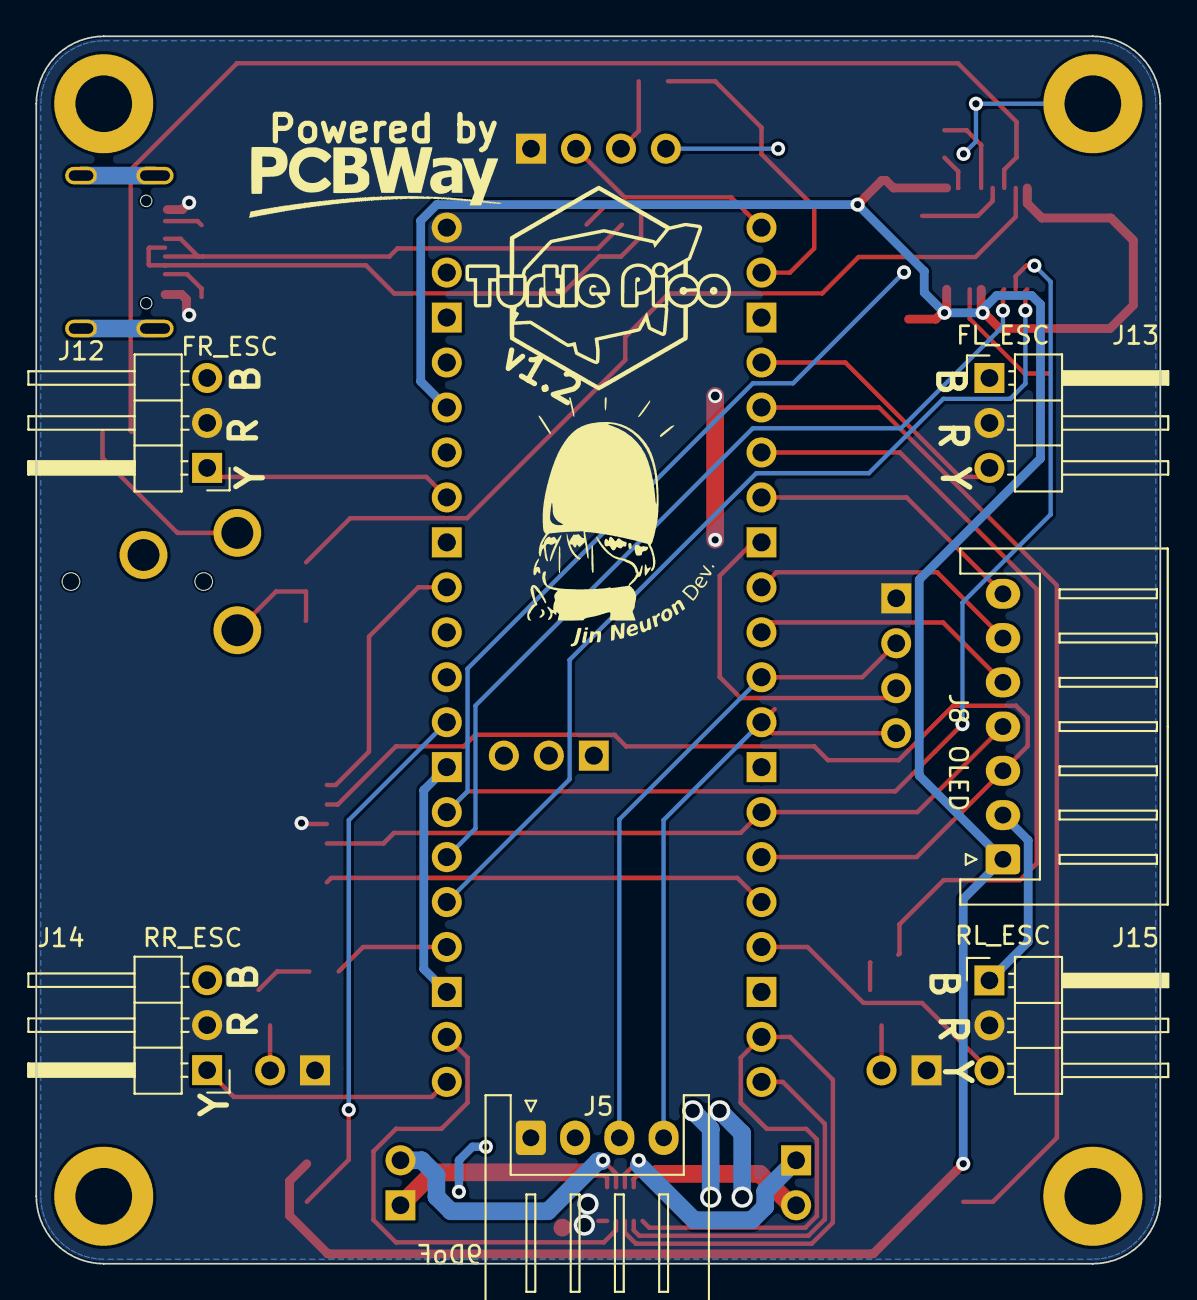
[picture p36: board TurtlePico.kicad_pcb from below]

Board: 2 copper layers, 63.5 x 69.3 mm, 40 parts (6 on the bottom side), 49 nets.

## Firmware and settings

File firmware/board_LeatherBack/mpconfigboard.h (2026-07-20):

// Board and hardware specific configuration
#define MICROPY_HW_BOARD_NAME "TurtlePico Leatherback model"
#define PICO_FLASH_SIZE_BYTES (16 * 1024 * 1024)
#define MICROPY_HW_FLASH_STORAGE_BYTES (PICO_FLASH_SIZE_BYTES - (2 * 1024 * 1024))
#define MICROPY_HW_MCU_NAME "RP2350"

// I2Cのデフォルト設定
#define MICROPY_HW_I2C0_SCL             (15)
#define MICROPY_HW_I2C0_SDA             (14)

// SPIのデフォルト設定
#define MICROPY_HW_SPI1_SCK             (10)
#define MICROPY_HW_SPI1_MOSI            (11)
#define MICROPY_HW_SPI1_MISO            (12) 

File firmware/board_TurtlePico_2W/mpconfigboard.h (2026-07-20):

// Board and hardware specific configuration
#define MICROPY_HW_BOARD_NAME "TurtlePico PICO2_W model"
// todo: We need something to check our binary size
#define MICROPY_HW_FLASH_STORAGE_BYTES          (PICO_FLASH_SIZE_BYTES - 1536 * 1024)
#define MICROPY_HW_MCU_NAME "RP2350"

// Enable networking.
#define MICROPY_PY_NETWORK 1
#define MICROPY_PY_NETWORK_HOSTNAME_DEFAULT     "TurtlePico"

// CYW43 driver configuration.
#define CYW43_USE_SPI (1)
#define CYW43_LWIP (1)
#define CYW43_GPIO (1)
#define CYW43_SPI_PIO (1)

// For debugging mbedtls - also set
// Debug level (0-4) 1=warning, 2=info, 3=debug, 4=verbose
// #define MODUSSL_MBEDTLS_DEBUG_LEVEL 1

#define MICROPY_HW_PIN_EXT_COUNT    CYW43_WL_GPIO_COUNT

// I2Cのデフォルト設定
#define MICROPY_HW_I2C0_SCL             (9)
#define MICROPY_HW_I2C0_SDA             (8)

// SPIのデフォルト設定
#define MICROPY_HW_SPI1_SCK             (10)
#define MICROPY_HW_SPI1_MOSI            (11)
#define MICROPY_HW_SPI1_MISO            (12) 

// If this returns true for a pin then its irq will not be disabled on a soft reboot
int mp_hal_is_pin_reserved(int n);
#define MICROPY_HW_PIN_RESERVED(i) mp_hal_is_pin_reserved(i)

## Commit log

2024-11-26 edit schematics
    [LED_Switch.kicad_sch, Motor.kicad_sch, RP2040.kicad_sch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]
2025-04-07 bugfix I2S soundplay finished...
    [main.py]
2025-05-04 change core to rp2350b and some pin out
    [Audio.kicad_sch, Connector.kicad_sch, LED_Switch.kicad_sch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]
2025-05-05 add some connectors
    [Audio.kicad_sch, Connector.kicad_sch, LED_Switch.kicad_sch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]
2025-05-05 change imu to BNO086
    [RP2350B.kicad_sch, Sensor.kicad_sch]
2025-05-05 set footprint
    [Audio.kicad_sch, Connector.kicad_sch, LED_Switch.kicad_sch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]
2025-05-05 add testpoint for gnd and pic of schematics
    [Connector.kicad_sch, Sensor.kicad_sch, TurtlePico-Minimal.kicad_pcb]
2025-05-05 change model name of minimal to advanced and name it "Leatherback"
    [Audio.kicad_sch, Connector.kicad_sch, LED_Switch.kicad_sch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]
2025-05-05 change kicad project name "Leatherback"
    [TurtlePico-Leatherback.kicad_pcb, TurtlePico-Leatherback.kicad_sch]
2025-05-08 put footprints and change schematics
    [Audio.kicad_sch, Connector.kicad_sch, LED_Switch.kicad_sch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]
2025-05-11 change schematics and complete wiring
    [Audio.kicad_sch, Connector.kicad_sch, LED_Switch.kicad_sch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]
2025-05-12 add gerber
    [TurtlePico-Leatherback-B_Cu.gbr, TurtlePico-Leatherback-B_Mask.gbr, TurtlePico-Leatherback-B_Paste.gbr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]
2025-08-22 some adjust PCB
    [TurtlePico-Leatherback.kicad_pcb]
2025-08-22 add nonWifi model
    [TurtlePico_nw-B_Cu.gbr, TurtlePico_nw-B_Mask.gbr, TurtlePico_nw-B_Paste.gbr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]
2026-02-20 add LTB example and more
    [Audio.kicad_sch, LED_Switch.kicad_sch, Motor.kicad_sch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]
2026-02-20 replace xh to qi
    [TurtlePico.kicad_pcb]
2026-02-20 update step v1.1
    [TurtlePico.kicad_pcb, TurtlePico_v1.1.step]
2026-02-22 update TurtlePico case
    [LowerCase.3mf, LowerCase.step, LowerCase_xh.3mf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]
2026-02-22 add board and st7789 lib
    [Audio.kicad_sch, LED_Switch.kicad_sch, LowerCase.3mf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]
2026-02-23 add Leatherback board firmware
2026-02-23 adjust ignore file
    [pins.csv]
2026-02-23 apply motor and car example to TurtlePico Firmware
2026-02-23 apply led example to TurtlePico Firmware
2026-02-23 apply led_web example to TurtlePico Firmware and remove ftes
2026-02-23 apply neopixel and motors example to TurtlePico
2026-02-23 apply sensors_web example to TurtlePico Firmware
2026-02-23 apply servo example to TurtlePico Firmware
2026-02-23 apply temperature and smarthome example to TurtlePico Firmware
2026-02-23 apply ultrasonic example to TurtlePico Firmware
2026-02-23 update firmware micropython v1.26.1
    [pins.csv]
2026-07-20 add v1.2 model
    [TurtlePico-B_Cu.gbr, TurtlePico-B_Mask.gbr, TurtlePico-B_Paste.gbr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]
2026-09-16 fix pcb conflict
    [TurtlePico.kicad_pcb]
2026-09-16 apply kicad version 10
    [TurtlePico.kicad_pcb, TurtlePico.kicad_sch]
2026-09-16 add v1.2 3d data
    [TurtlePico_v1.2.step]
2026-09-16 add new case/package 3d data/photo
    [LowerCase_HighQI.3mf, LowerCase_LowQI.3mf, LowerCase_XH.3mf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]
2026-09-29 add example 3D_Data
    [BatCase.3mf, Bottom.3mf, CarBody.3mf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]
